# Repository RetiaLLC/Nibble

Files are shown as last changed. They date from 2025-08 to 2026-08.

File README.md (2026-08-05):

# Nibble
Open Source Nibble Release

Follow the assembly guide here:
Play Video (https://www.youtube.com/watch?v=EOClEx3fuvY&t=1s)

My talk on Meshtastic:
Play Video (https://www.youtube.com/watch?v=rvsCFDF0pyk)

Meshtastic Config (compile your own firmware)

The Nibble variants are merged upstream in Meshtastic; our pinned, both-LEDs build lane is **[RetiaLLC/ScriptkittyMeshtastic](https://github.com/RetiaLLC/ScriptkittyMeshtastic)**:

RP2040: env `nibble-rp2040` — workflow [`compile_rp2040_nibble.yaml`](https://github.com/RetiaLLC/ScriptkittyMeshtastic/blob/main/.github/workflows/compile_rp2040_nibble.yaml)

ESP32-S3: env `nibble-esp32` — workflow [`compile_opensource_nibble_esp32s3.yaml`](https://github.com/RetiaLLC/ScriptkittyMeshtastic/blob/main/.github/workflows/compile_opensource_nibble_esp32s3.yaml)

# LoRa Nibble  

The **Nibble** is a small, open source LoRa radio node designed to be your first piece of off-grid infrastructure. It was created by **Kody Kinzie and the Retia team (Zac Beran, Felix Orozco)** for the 2024 Chaos Communication Congress in Germany and released as open hardware at the 2025 Hackers On Planet Earth conference.  

Over **500 Nibbles have been made** worldwide, and the design is shared here so you can build your own. The board is sized to fit inside a **1 inch PVC pipe**, making it easy to weatherproof and deploy as a permanent or portable infrastructure node.  

---

## Features  
- Fits inside standard 1 inch PVC pipe for protection and mounting  
- Works with **Meshtastic** for off-grid communication  
- Supports either **ESP32-S3** (Wi-Fi/Bluetooth) or **RP2040** (low power) microcontrollers  
- Uses **RFM95 LoRa modules** (868 MHz EU or 915 MHz US)  
- Expandable with I²C sensors for telemetry  
- Supports private channels, GPS sharing, and sensor reporting  
- Open source hardware and firmware  

---

## Bill of Materials  
- 1x Nibble PCB (order from JLCPCB, PCBWay, OSH Park, etc.)  
- 1x Microcontroller (ESP32-S3 or RP2040)  
- 1x RFM95 LoRa radio module (868 MHz or 915 MHz)  
- 1x Spring antenna or U.FL connector and external antenna  
- 1x 330 Ω resistor (1206 size) 
- 2x 10k Ω resistors (1206 size)
- 1x LED indicator  

**Tools required:** soldering iron, solder, tweezers or pliers, and a laptop with USB-C cable.  

---

## Assembly Instructions  
1. Solder the **resistors** (330 Ω and two 10k Ω).  
2. Install the **microcontroller** into the designated footprint. Only one microcontroller can be used at a time.  
   - Use ESP32-S3 if you want Bluetooth and Wi-Fi connectivity.  
   - Use RP2040 if you want a lower power build for solar or battery use.  
3. Solder the **LoRa radio module**. Align it carefully with the silkscreen outline.  
4. Solder the **antenna connector**. Use either the spring antenna or the U.FL connector, not both.  
5. Solder the **LED indicator**. The negative leg goes to the square pad.  

⚠️ **Important:** Always connect an antenna before powering or transmitting. Running the board without one can permanently damage the radio.  

---

## Firmware Installation  

### ESP32-S3   
1. Visit the browser flasher at **[scriptkitty.sh](https://scriptkitty.sh)**.  
2. Hold the **BOOT** (B) button while plugging in the board.  
3. Select your Nibble from the device list.  
4. Select the Nibble Meshtastic firmware and flash.  
5. Once uploaded, unplug and reconnect the board.  

### RP2040  
Easiest: use the browser flasher at **[scriptkitty.sh](https://scriptkitty.sh)** — pick the *Meshtastic — Open Source Nibble (RP2040)* card and it walks you through the drag-and-drop.

Manual:
1. Get the `.uf2` from **[scriptkitty.sh](https://scriptkitty.sh)** (Download `.uf2`), or from the canonical build release: **[ScriptkittyMeshtastic releases](https://github.com/RetiaLLC/ScriptkittyMeshtastic/releases/latest)** (`nibble-rp2040.zip` → extract the `.uf2`).  
2. Hold the **BOOTSEL** button while plugging in the board.  
3. The board mounts as a USB drive named `RPI-RP2`.  
4. Drag and drop the `.uf2` onto the drive. The board reboots automatically — both the ear LED and the onboard NeoPixel blink a heartbeat.  

**Alternative firmware — MeshCore:** the RP2040 Nibble also runs **[MeshCore](https://github.com/meshcore-dev/MeshCore)**, a lightweight off-grid mesh. Flash it from **[scriptkitty.sh](https://scriptkitty.sh)** (the *MeshCore — Open Source Nibble (RP2040)* card), or grab the `.uf2` from the **[MeshCore release](https://github.com/RetiaLLC/Nibble/releases/tag/meshcore-rp2040-v1.16.0)** (hardware-verified — radio init + TX confirmed on a real Nibble). Same BOOTSEL drag-and-drop.  

---

## Meshtastic Setup  
1. Connect to the Nibble using the **Meshtastic app** or via **USB serial**.  
   - Bluetooth default PIN (ESP32 only): `123456`.  
2. Set your **region** (US915 or EU868).  
3. Give the device a **short name** and **long name**.  
4. Join or create a **private channel**. You can share access with friends using QR codes.  

---

## Example Uses  
- Off-grid communication at festivals or protests  
- Emergency infrastructure during natural disasters  
- Remote telemetry for weather stations  
- GPS tracking in outdoor environments  
- Long range remote control or IoT projects  

---

## Community and Resources  
- Flashing firmware (browser flasher): [scriptkitty.sh](https://scriptkitty.sh)  
- Firmware source & release builds: [RetiaLLC/ScriptkittyMeshtastic](https://github.com/RetiaLLC/ScriptkittyMeshtastic/releases/latest)  
- Meshtastic documentation: [meshtastic.org](https://meshtastic.org)  
- Community projects and support: [Retia Discord](https://discord.gg/cJHNswdSTz)

### Project Images

#### Front & Back
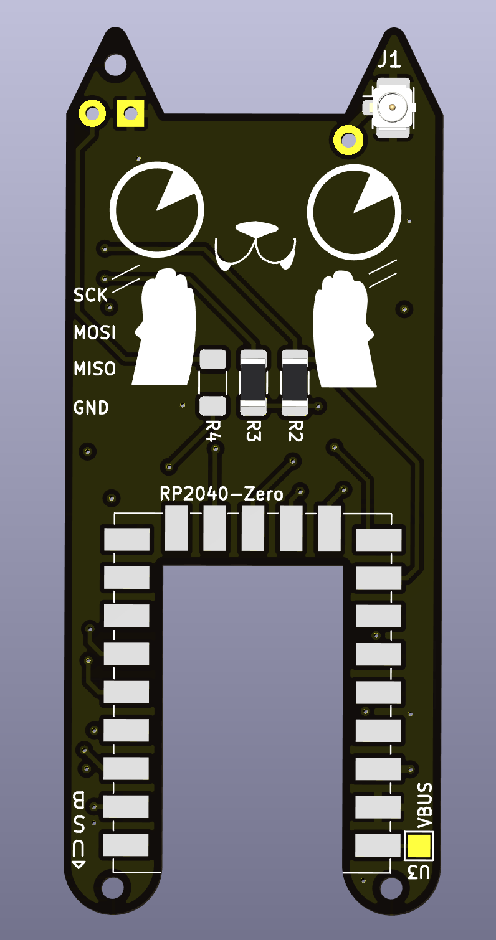
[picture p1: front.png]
Front

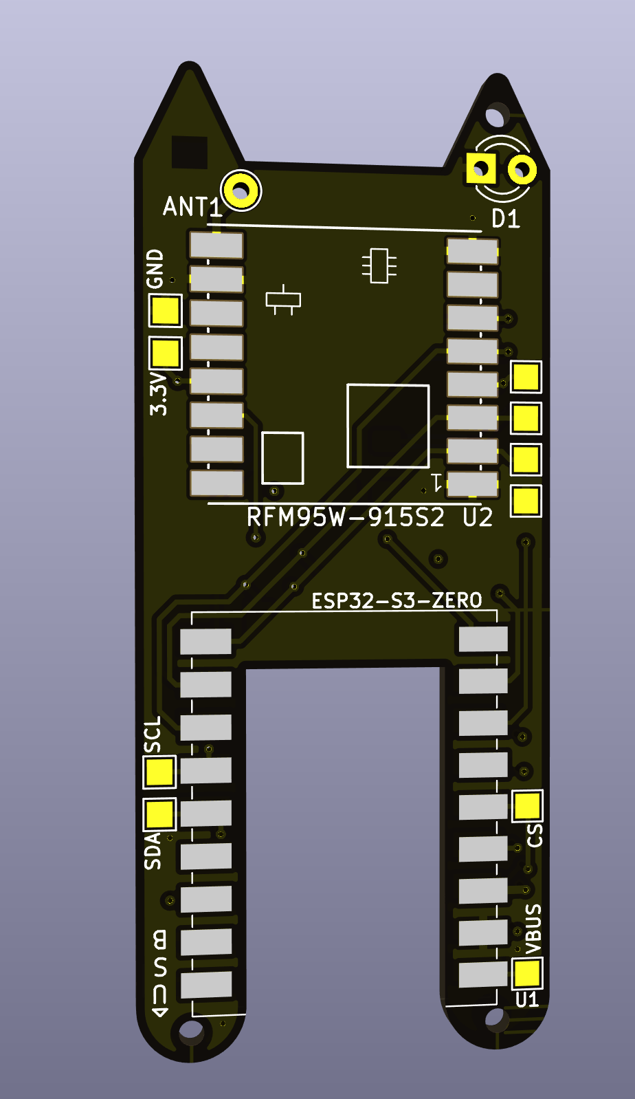
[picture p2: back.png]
Back


#### Kit & Sensor
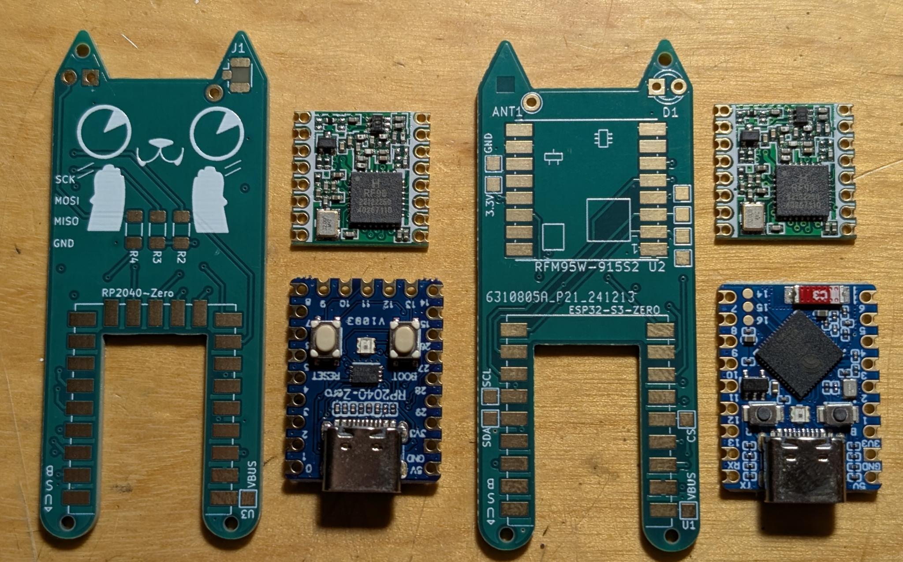
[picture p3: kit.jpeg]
Kit

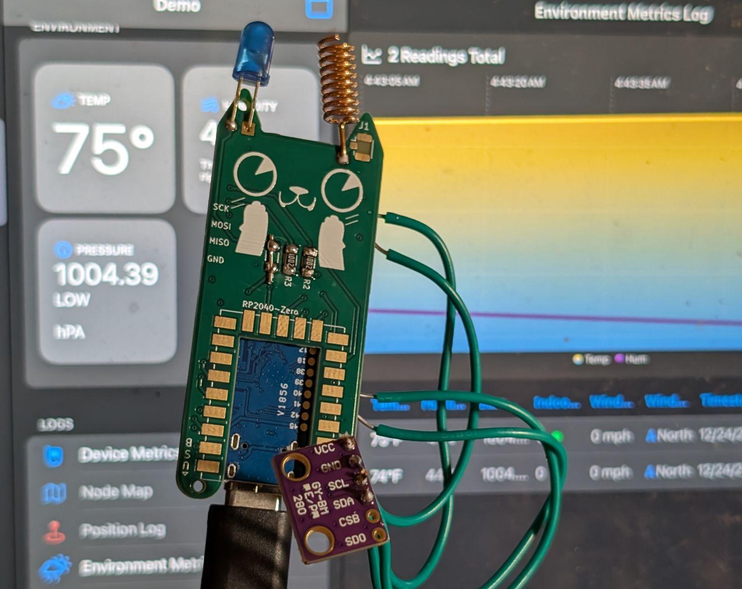
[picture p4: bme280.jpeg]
BME280 Sensor


#### Schematic
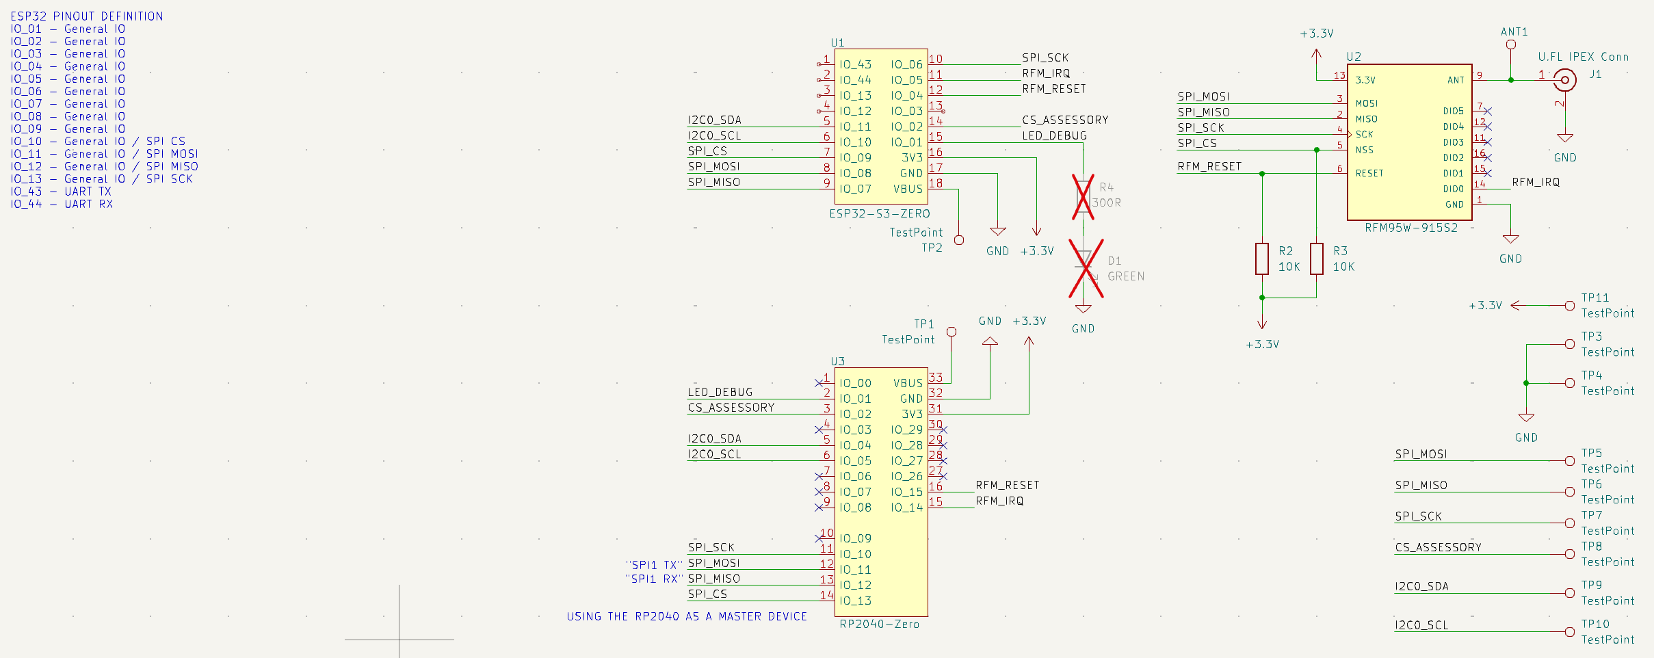
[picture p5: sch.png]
Schematic


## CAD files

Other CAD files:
open_sourced_nibble_v1_board_outline/nibble_rev01.FCStd

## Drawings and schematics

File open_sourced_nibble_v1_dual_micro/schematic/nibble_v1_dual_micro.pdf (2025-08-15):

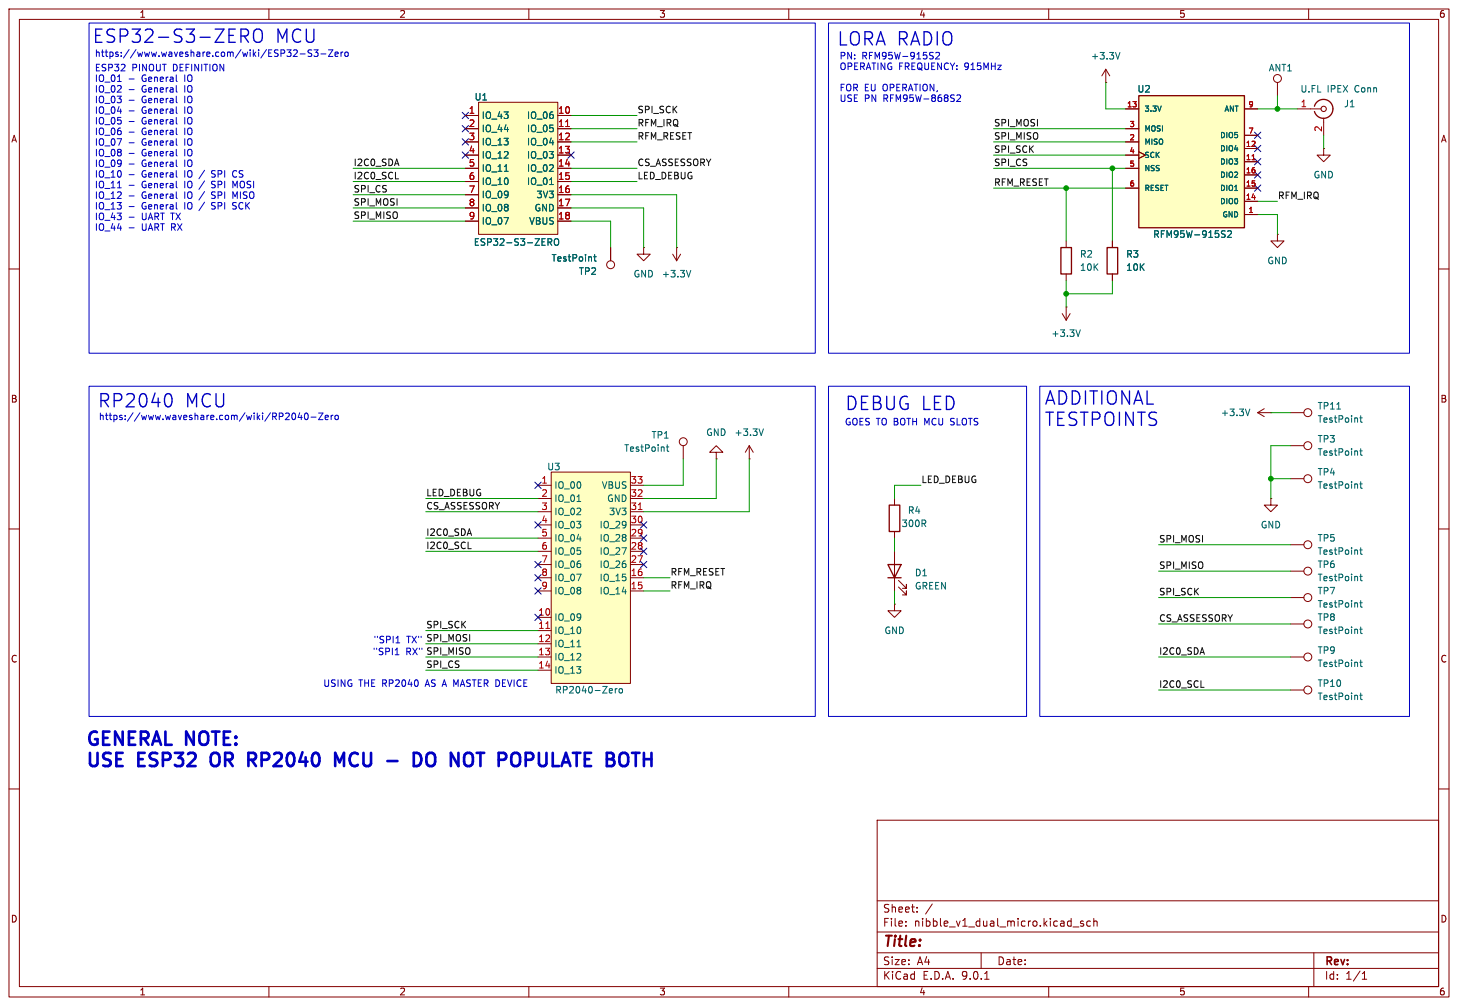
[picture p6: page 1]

https://www.waveshare.com/wiki/ESP32-S3-Zero ESP32 PINOUT DEFINITION

IO_01 - General IO
IO_02 - General IO
IO_03 - General IO
IO_04 - General IO
IO_05 - General IO
IO_06 - General IO
IO_07 - General IO
IO_08 - General IO
IO_09 - General IO
IO_10 - General IO / SPI CS
IO_11 - General IO / SPI MOSI
IO_12 - General IO / SPI MISO
IO_13 - General IO / SPI SCK
IO_43 - UART TX
IO_44 - UART RX

GOES TO BOTH MCU SLOTS RP2040 MCU
https://www.waveshare.com/wiki/RP2040-Zero

"SPI1 RX" USING THE RP2040 AS A MASTER DEVICE

GENERAL NOTE:
USE ESP32 OR RP2040 MCU - DO NOT POPULATE BOTH

Id: 1/1 Title: File: nibble_v1_dual_micro.kicad_sch Sheet: /

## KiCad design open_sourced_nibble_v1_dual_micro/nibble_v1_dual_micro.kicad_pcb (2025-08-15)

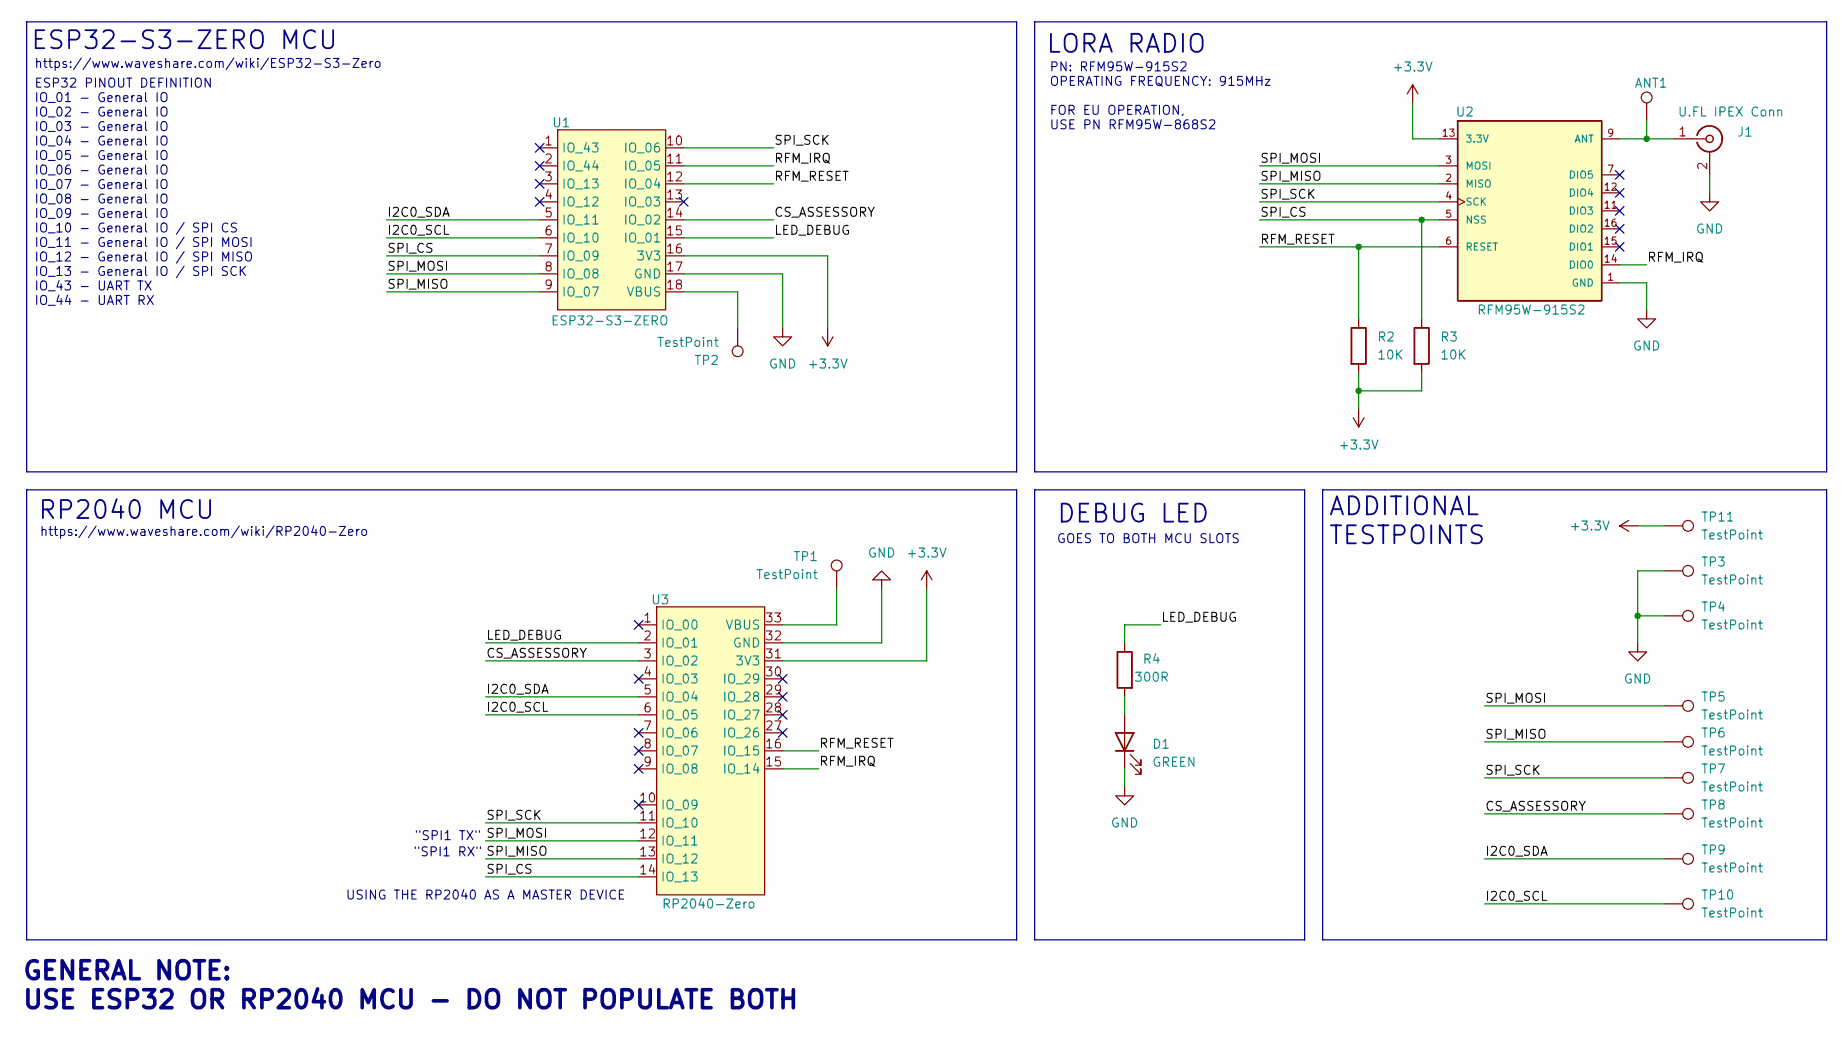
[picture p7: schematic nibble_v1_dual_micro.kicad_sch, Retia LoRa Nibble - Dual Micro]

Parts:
ANT1: TestPoint; TestPoint_THTPad_D2.0mm_Drill1.0mm
D1: GREEN; LED_D3.0mm; LCSC Part # C98224
J1: U.FL IPEX Conn; LCSC_U.FL_Hirose_U.FL-R-SMT-1_Vertical; LCSC Part # C5137195
R2: 10K; R_1206_3216Metric_Pad1.30x1.75mm_HandSolder; LCSC Part # C132649
R3: 10K; R_1206_3216Metric_Pad1.30x1.75mm_HandSolder; LCSC Part # C98220
R4: 300R; R_1206_3216Metric_Pad1.30x1.75mm_HandSolder; LCSC Part # C137315
TP1, TP2, TP3, TP4, TP5, TP6, TP7, TP8, TP9, TP10, TP11: TestPoint; TestPoint_Pad_1.5x1.5mm
U1: ESP32-S3-ZERO; waveshare_esp32_s3_smt&tht
U2: RFM95W-915S2; XCVR_RFM95W-915S2
U3: RP2040-Zero; waveshare_rp2040_zero

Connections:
+3.3V: R2.2, R3.2, TP11.1, U1.16 (3V3), U2.13 (3.3V), U3.31 (3V3)
/CS_ASSESSORY: TP8.1, U1.14 (IO_02), U3.3 (IO_02)
/I2C0_SCL: TP10.1, U1.6 (IO_10), U3.6 (IO_05)
/I2C0_SDA: TP9.1, U1.5 (IO_11), U3.5 (IO_04)
/LED_DEBUG: R4.1, U1.15 (IO_01), U3.2 (IO_01)
/RFM_IRQ: U1.11 (IO_05), U2.14 (DIO0), U3.15 (IO_14)
/RFM_RESET: R2.1, U1.12 (IO_04), U2.6 (RESET), U3.16 (IO_15)
/SPI_CS: R3.1, U1.7 (IO_09), U2.5 (NSS), U3.14 (IO_13)
/SPI_MISO: TP6.1, U1.9 (IO_07), U2.2 (MISO), U3.13 (IO_12)
/SPI_MOSI: TP5.1, U1.8 (IO_08), U2.3 (MOSI), U3.12 (IO_11)
/SPI_SCK: TP7.1, U1.10 (IO_06), U2.4 (SCK), U3.11 (IO_10)
GND: D1.1 (K), J1.2 (Ext), TP3.1, TP4.1, U1.17 (GND), U2.1 (GND), U2.8 (GND), U2.10 (GND), U3.32 (GND)
unnamed: D1.2 (A), R4.2
unnamed: ANT1.1, J1.1 (In), U2.9 (ANT)
unnamed: TP2.1, U1.18 (VBUS)
unnamed: TP1.1, U3.33 (VBUS)

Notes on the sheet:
PN: RFM95W-915S2 OPERATING FREQUENCY: 915MHz FOR EU OPERATION, USE PN RFM95W-868S2
RP2040 MCU
ESP32-S3-ZERO MCU
GOES TO BOTH MCU SLOTS
ADDITIONAL TESTPOINTS
DEBUG LED
"SPI1 TX"
LORA RADIO
"SPI1 RX"
https://www.waveshare.com/wiki/RP2040-Zero
USING THE RP2040 AS A MASTER DEVICE
https://www.waveshare.com/wiki/ESP32-S3-Zero
ESP32 PINOUT DEFINITION IO_01 - General IO IO_02 - General IO IO_03 - General IO IO_04 - General IO IO_05 - General IO IO_06 - General IO IO_07 - General IO IO_08 - General IO IO_09 - General IO IO_10 - General IO / SPI CS IO_11 - General IO / SPI MOSI IO_12 - General IO / SPI MISO IO_13 - General 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
GENERAL NOTE: USE ESP32 OR RP2040 MCU - DO NOT POPULATE BOTH

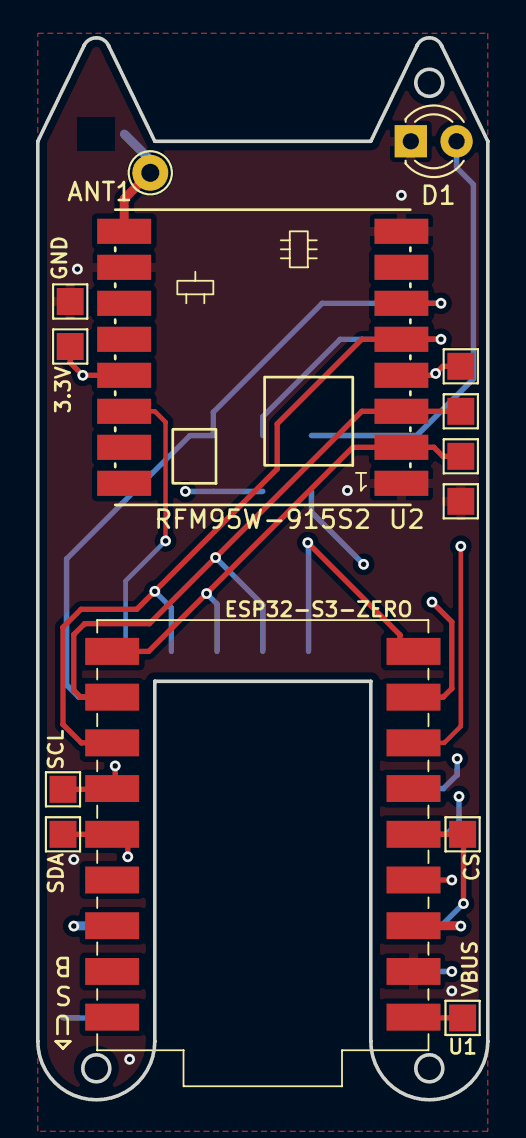
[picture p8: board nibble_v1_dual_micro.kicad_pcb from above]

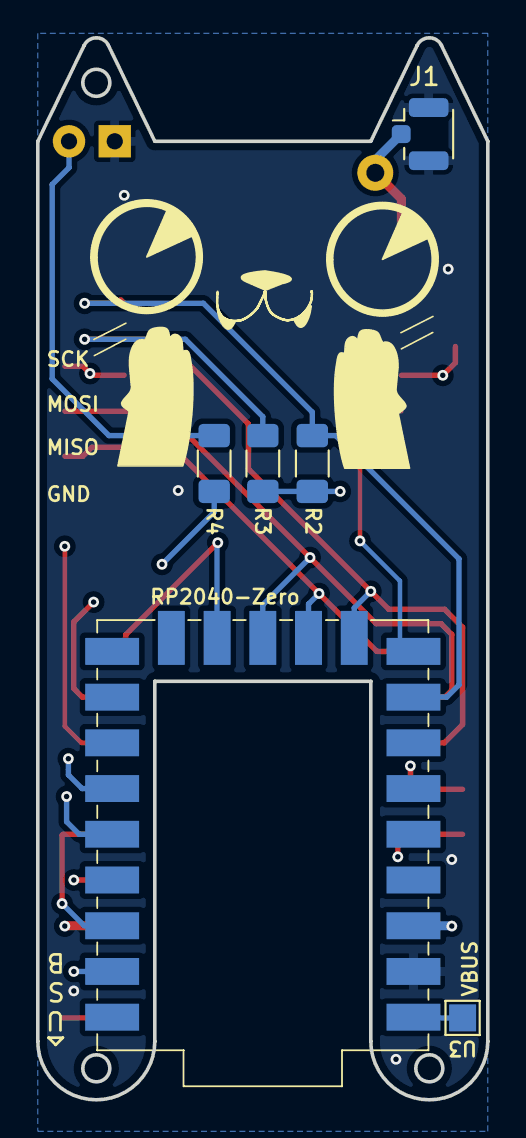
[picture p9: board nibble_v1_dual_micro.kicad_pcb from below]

Board: 4 copper layers, 25.0 x 59.0 mm, 20 parts (6 on the bottom side), 16 nets.

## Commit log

2025-08-15 Release the Nibble to the world!
    [nibble_rev01-Sketch.dxf, nibble_rev01.FCStd, nibble_v1_dual_micro.kicad_pcb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]
2026-03-02 Upload this file to JLCPCB or PCBWay to make PCBS!
2026-03-03 Update README to clarify assembly guide reference
2026-03-03 Adding universal gerbers for PCB making
    Upload this file to JLCPCB or PCBWay to make PCBS!
2026-03-03 Update firmware links for RP2040 and ESP32s3
2026-04-11 Update resistor specifications in README
    Specify resistor sizes in the components list.
2026-08-02 Point firmware to the Robo-Retia release + flasher; drop duplicated binary (#3)
    - Compile-your-own links: stale Sparkling-Ice/retia-boards -> the real build
    lane RetiaLLC/Robo-Retia-Meshtastic (variants are merged upstream; the lane
    carries the pinned both-LEDs build).
    - RP2040 + ESP32-S3 firmware install now point at the scriptkitty.sh flasher,
    with the canonical .uf2 sourced from the Robo-Retia release.
    - Community links: nugget.dev -> scriptkitty.sh + the release page.
    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
